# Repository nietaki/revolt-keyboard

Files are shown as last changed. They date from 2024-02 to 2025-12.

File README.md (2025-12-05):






# Revolt Keyboard

> **Revolt** - a split ergonomic keyboard prioritising ease of adoption, flexibilty, easy build+repair, and partial upgrades
> 

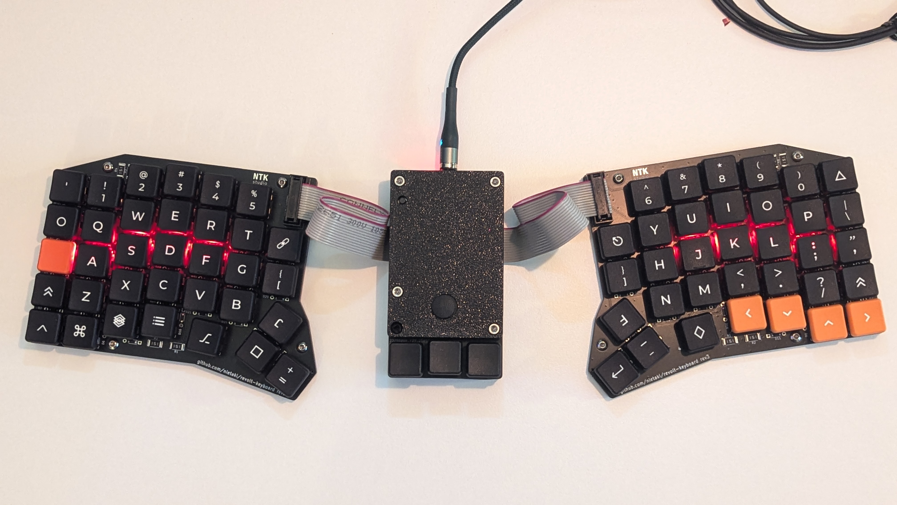
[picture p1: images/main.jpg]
final result


## Why call it “Revolt”?

1. It’s heavily inspired by [Redox](https://github.com/mattdibi/redox-keyboard), an amazing open-source keyboard, that is still my daily driver
2. It’s revolting against the popular design philosophy of keybords like Sofle, Lily58 or Corne, which prioritise a compact footprint over other qualities
3. Some might find it “revolting”, since its looks are secondary to its features

More info on the design philosophy behind revolt in the [Revolt Manifesto](./Revolt_Manifesto.md)

## TL;DR

It’s a 68(+3) key, wired, choc-based split ergonomic keyboard running QMK. Instead of being split into 2 halves, it’s split into 3 parts: left input, right input and the center one called “commander”

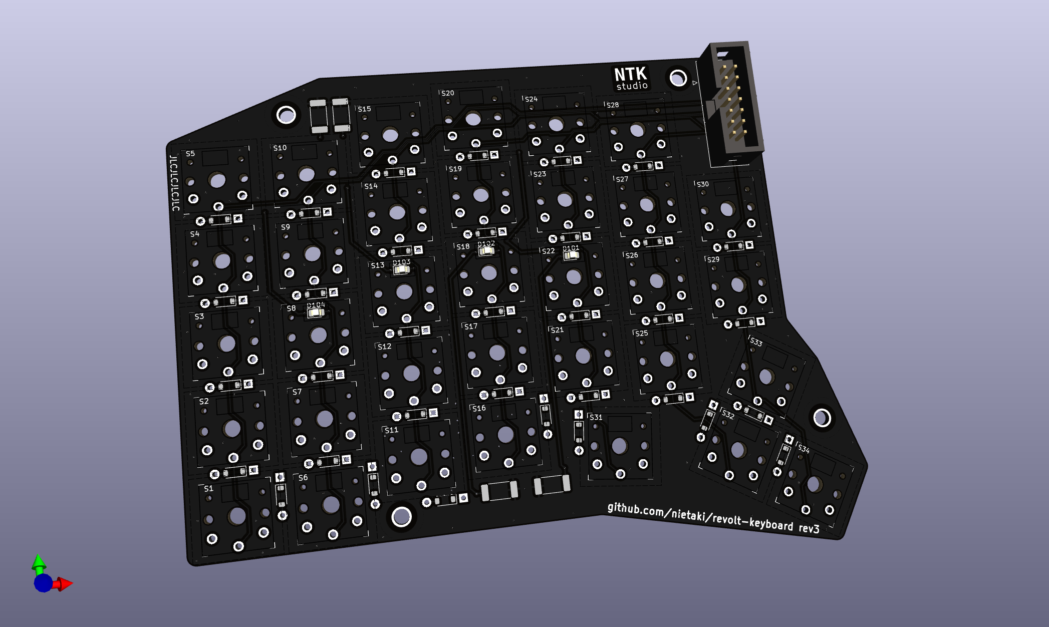
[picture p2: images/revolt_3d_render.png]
input board


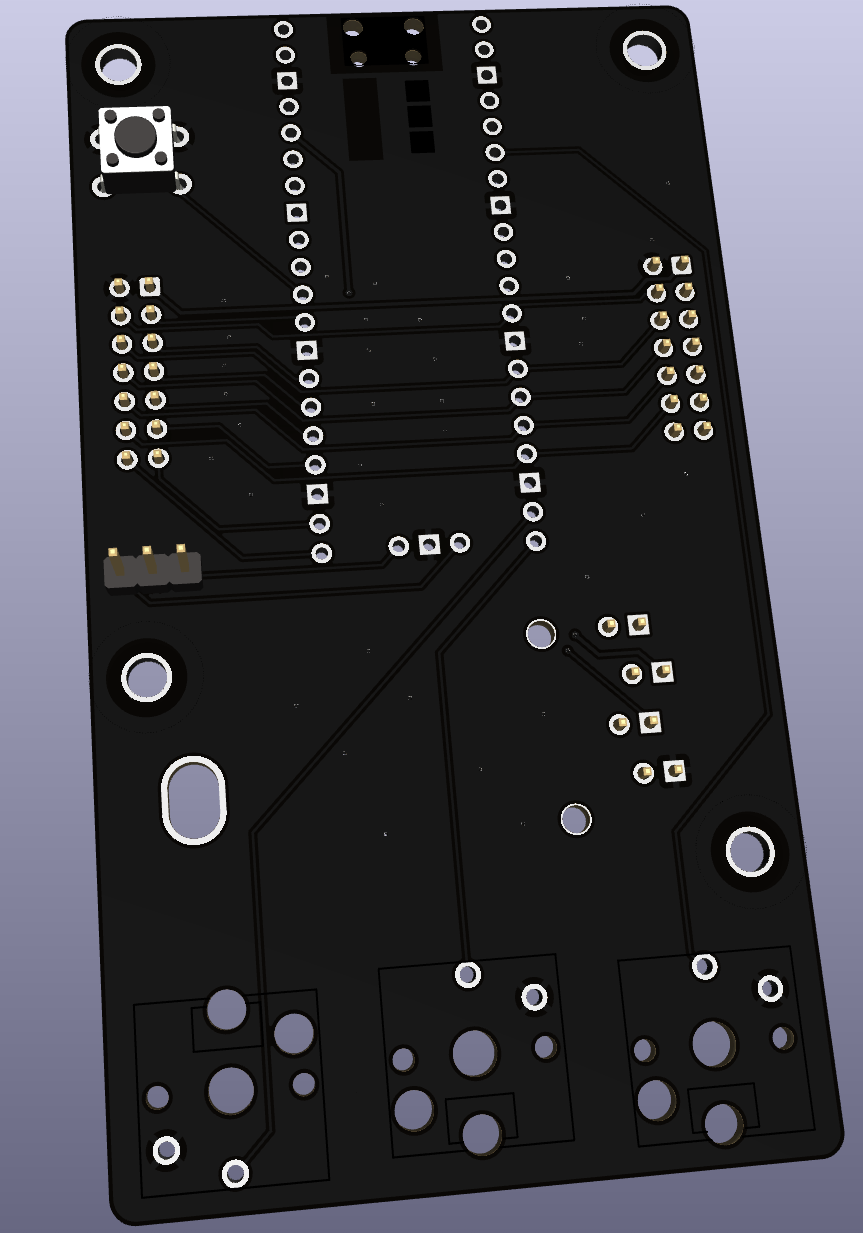
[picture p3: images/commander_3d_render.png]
commander board


The left and right input parts are “dumb”, and contain only the switches and diodes to make 7x5 matrix work, plus optional LEDs under home keys.

The case will be made with low profile + tenting in mind (with multiple tenting angles possible), with two versions: for soldered switches without a top plate and hotswap with a top plate.

The commander board should lend itself to experimenting with different pointing devices. 
Current has connectors for a PSP 3000 joystick. It should be easy to create versions that support other pointing devises, like a trackball, a Cirque touchpad or other joysticks.

## How To...

### ...build the keyboard?

Follow the [build video](https://www.youtube.com/watch?v=ghhF0bAFxww). You can find more support under the links [here](https://ntkstudio.net/products/revolt-keyboard/#support).

### ...make the cases?

The case files are available on [Printables](https://www.printables.com/model/1439208-revolt-keyboard-cases-rev1) and [Thingiverse](https://www.thingiverse.com/thing:7166363).

### ...compile the firmware?

```bash
$ cd /path/to/qmk_firmware
$ qmk compile -kb revolt/rev1 -km default
#  It should generate the firmware file
$ stat ./revolt_rev1_default.uf2
```
### ...flash the firmware?

1. Unplug the commander board
1. Push the `bootsel` button on the RP2040
1. While having the button pushed in, connect the commander board to the computer

A virtual drive (?) for the rpi should be discovered by the computer. 
Drag the compiled firmware file into it. 
RPi will reboot and run the firmware.

## FAQ

### Why do you hate Sofle/Lily58/Corne?

I don’t! They’re beautiful keyboards, designed with love and forethought, all of them with passionate communities. They just don’t fit the criteria of what I’m looking for in an ergonomic keyboard that can be used just as easily for programming and gaming, especially for people coming from “regular” keyboards. I wanted to make a keyboard that’s perfect for me and other like-minded people.

### No wireless version?

I’m not ruling out a wireless version in the future. I’d like to perfect the wired version to my liking and see what kinds of compromises make sense.

But with Revolt being open source, there’s no reason for anyone interested not to take a crack at it themselves.

## Workflow

1. Build matrix, outline and pcb in yml
2. generate kicad pcb
3. Create the kicad project
4. Replace the kicad pcb file with the generated one
5. Replace the switch footprints with the ones from keyswitch library
5. Create the matrix schematic by hand, with the diode numbers matching the swich numbers from pcb
6. **change the diode numbers in the pcb to line up with the switch numbers in the pcbnew**
  - this can be automated together with the switch numbers, I think
7. Add hierarchical net names
7. Update the schematic from the pcb band the other way until stuff is consistent.
8. ...
8. Draw the rest of the owl

## Special thanks

Projects that helped or inspired me:

- https://github.com/mattdibi/redox-keyboard
- https://github.com/daprice/keyswitches.pretty/ - adapted some footprints from this brilliant library
- https://flatfootfox.com/ergogen-introduction/
- https://github.com/labtroll/KiCad-DesignRules/tree/main
- https://docs.ergogen.xyz/
- https://github.com/sol/KiCad-RP-Pico

## License



[Revolt Keyboard](https://github.com/nietaki/revolt-keyboard)© 2024 by [@nietaki](https://nietaki.com/) is licensed under [CC BY-SA 4.0](http://creativecommons.org/licenses/by-sa/4.0/?ref=chooser-v1)

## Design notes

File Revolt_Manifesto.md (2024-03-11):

# Revolt Manifesto

## Design principles

### Enough keys to be single layer friendly

Keyboards smaller than Ergodox/Redox/Ergodash can’t fit many of the keys needed for every day use, forcing the users to rely on layers and dual-function keys. Working with a single layer 95% of the time allows you to use Revolt for anything you need it for, without crafting and memorizing shortcuts or being careful with dual-function keys.

That’s not to say you can’t use a layered setup you like - QMK allows for many layers and advanced functions, as you can see in the [configurator](https://config.qmk.fm/#/redox/rev1/base/LAYOUT).

I personally use layer 2 mainly for function keys and media keys in my Redox.

I’d argue this also has a positive impact on the typing speed. Many people argue that the main factor in the typing speed is not having to move your fingers much (with fewer keys, more layers and possibly something like the Colemak layout). I believe having to use key combos or different behaviour on key tap and key hold to input characters slows down your typing. The mental load to keep up with a complicated setup doesn’t help either. 

### Ease of adoption

People adopting Revolt can leverage their muscle memory with minimal changes, thanks to the `CTRL` and `META/WIN/CMD` keys in their regular locations and the flexibility of QMK.  

### Ergonomics

This one might seem pretty obvious, but hear me out.

The reason I first got into ergonomic keyboards was the RSI I was getting from long hours of coding early in my career - I was getting terrible wrist pain after hours of coding early in my career. I got a [Microsoft Sculpt Ergonomic Keyboard](https://www.google.com/search?q=microsoft+sculpt+ergonomic+keyboard&tbm=isch), which instantly made the problem go away.

I had a number of those throughout the years (5 keyboard+mouse sets?) and I loved them, but they kept on breaking. I got better at fixing them, cleaning and replacing the key stabilizers, but I kept having to buy new ones - and I think the keyboard is out of production by now…

This made it obvious to me I needed a mechanical keyboard that still had the ergonomics I was looking for - a stable keyboard with split layout with tenting and a good amount of keys.

I built myself a custom Redox and bought some wristpads for it - I still use it to this day. But I’d still prefer a lower profile keyboard with a pointer device in the middle (a touchpad, a trackball, or a Thinkpad-style trackpoint). 

This is where Revolt comes in - I hope I can have it all (and more) with this design

I’m trying to achieve good ergonomics with:

- Case designed with tenting in mind
- Keys closer together thanks to smaller footprints of Kailh Choc keycaps
- Keys closer to the desk surface (again thanks to Kailh Choc switches and a purpose-designed case)
- A more aggressive pinky stagger than some of the other designs

### Bang for buck

I wanted to keep the build affordable and simple, without sacrificing any of the other priorities. The simplest non-hotswap version should be doable for around 80 EUR, with not much more cost for a version with 3d-printed tenting case.

I want the design to lend itself to higher end versions, with hot-swap sockets and a top plate, integrated touchpad, and possibly 2 microcontrollers with wireless communication (all hopefully to come in future versions)

### Easy to build/fix

I’ve had keyboards in the past where the failure mode was the USB socket breaking, and replacing the microcontrollers (or reconfiguring the keyboard to connect from the other half) was more of a pain than I would like.

Similarly, there are some designs which are difficult to fix when a single component fails.

I like the idea of a “forever keyboard” that will serve you for decades with minimal maintenance. The microcontroller being on a separate PCB and easily swappable makes the whole setup quick and easy to fix in the future.

All the solder joints should be easy to access, solder or desolder without special tools. The case should be easy to make with any 3d printer.

### Function over form

Many keyboard designs prioritize minimalistic wireless aesthetics over ergonomics or other aspects of the build.

Revolt is aiming for the best long-term experience for the keyboard’s users, builders and developers while sporting an unapologetically utilitarian look.

### Easy to iterate on and (partially) upgrade

Usually the keyboard you first build/buy is the keyboard you’re stuck with, with the exception of changing switches or keycaps.

With Revolt you can keep the sides to experiment with different pointing devices in the center part, or keep the center part and play with different layouts in your left/right parts while keeping the center part that works for you. All that with minimal effort and cost.

With a standardized connection between the commander board and the input parts it’s easier, quicker and cheaper to iterate on the individual aspects of the keyboard. Want to try a new pointing device? Make some small changes to the commander board and solder it together without changing your input parts. Got an idea for a better key layout? You can make a revision of the input pcb without ever touching the microcontroller.

### Ease of layout changes / firmware programming

With most split keyboards, when you update your layout, you need to flash the firmware in both halves of the keyboard, which can be a pain and require some cable juggling. And you will be messing with the layout when you first get the keyboard :D

With a single microcontroller you don’t need to reconnect anything, you just reset the keyboard, flash it, and you’re done!

### Open source

It took a lot of open source work (KiCad, QMK, footprint libraries, microcontrollers) to make designing keyboards as easy and fun as it is right now. I’d like to pay it forward by reducing the barrier of entry for people to make a keyboard they’ll love using.

I might consider selling pre-made Revolt components, but the designs will always be open-source and anyone will be able their own unit from scratch.

## How is it different from Sofle/Lily58/Corne?

1. It has 68 keys (as opposed to 42 in Corne, 58 in Sofle and Lily58). It allows for `CTRL` and `META/WIN/CMD` keys in their regular location, arrow keys in the first layer and basically all of TKL ISO 104 keys, minus the function row and some of the  `HOME` / `END` / `PGUP` / `PGDOWN` keys
2. It has more thumb keys, in easy to reach locations
3. It uses just one microcontroller, making it easier to change the the layout/firmware

## How is it different from Redox?

1. It can be lower profile since the microcontroller isn’t mounted under the PCBs and Revolt v1 is designed with Kailh Choc switches in mind
2. It uses exclusively 1u keys, making it easier and cheaper to buy a keycap set for it. The 1.5u keys in Redox don’t have much of a benefit, but they make the overall keyboard dimensions bigger.
3. The pinky keys are placed lower to make them easier to reach - I struggle to press `Q` with my pinky on my Redox
4. All solder joints are accessible without the need to desolder the microcontroller
5. It uses just one microcontroller, making it easier to change the the layout/firmware

### How is it different from Zodiark?

> ⚠️ TODO

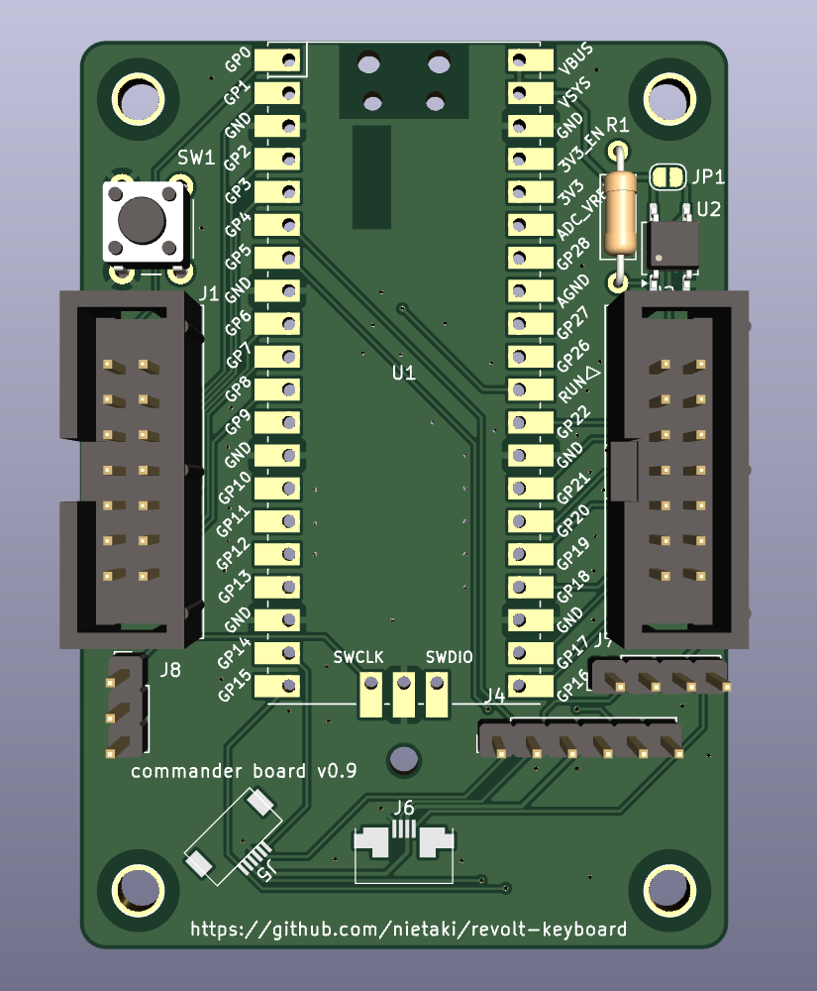
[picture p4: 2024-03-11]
images/3d_revolt_commander_0_9.png

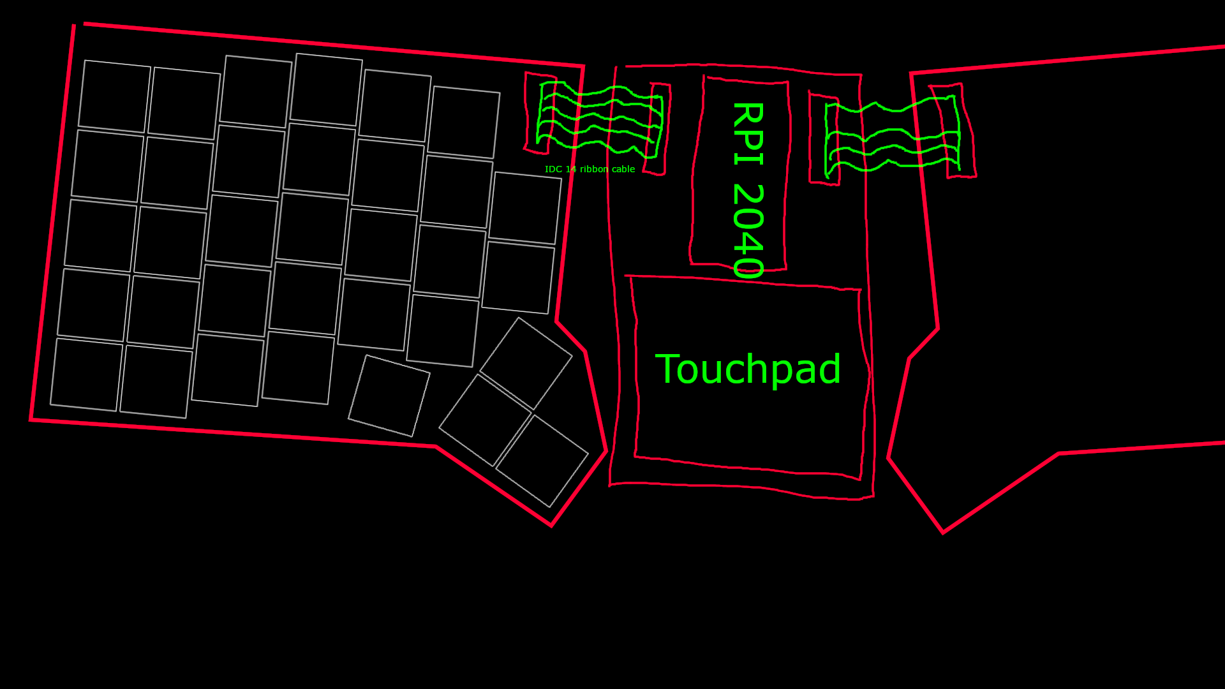
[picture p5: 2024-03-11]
images/revolt_idea.png

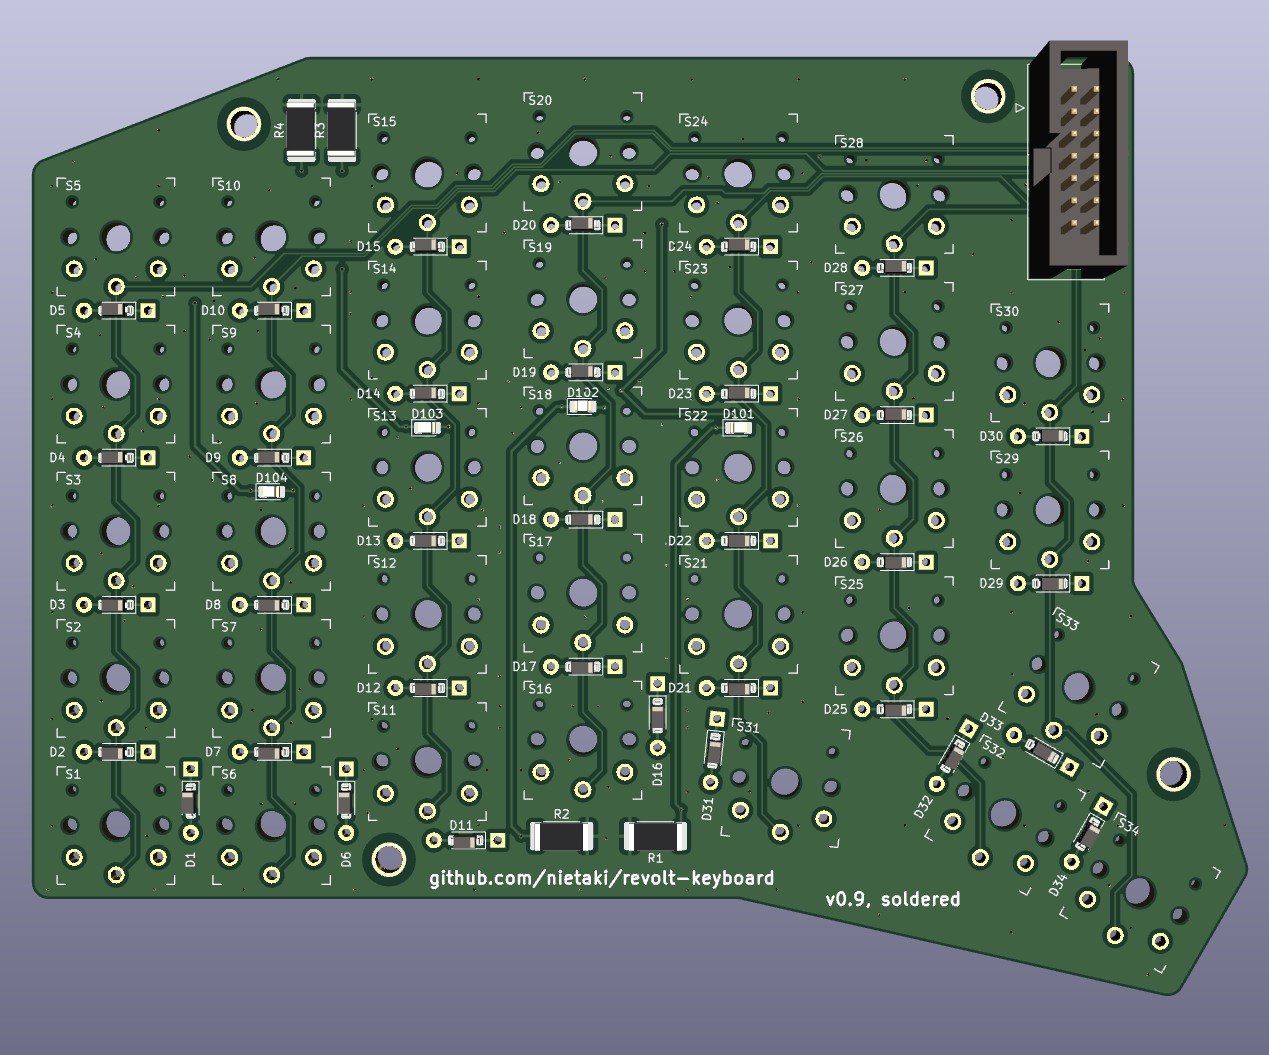
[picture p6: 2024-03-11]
images/3d_revolt_0_9.png

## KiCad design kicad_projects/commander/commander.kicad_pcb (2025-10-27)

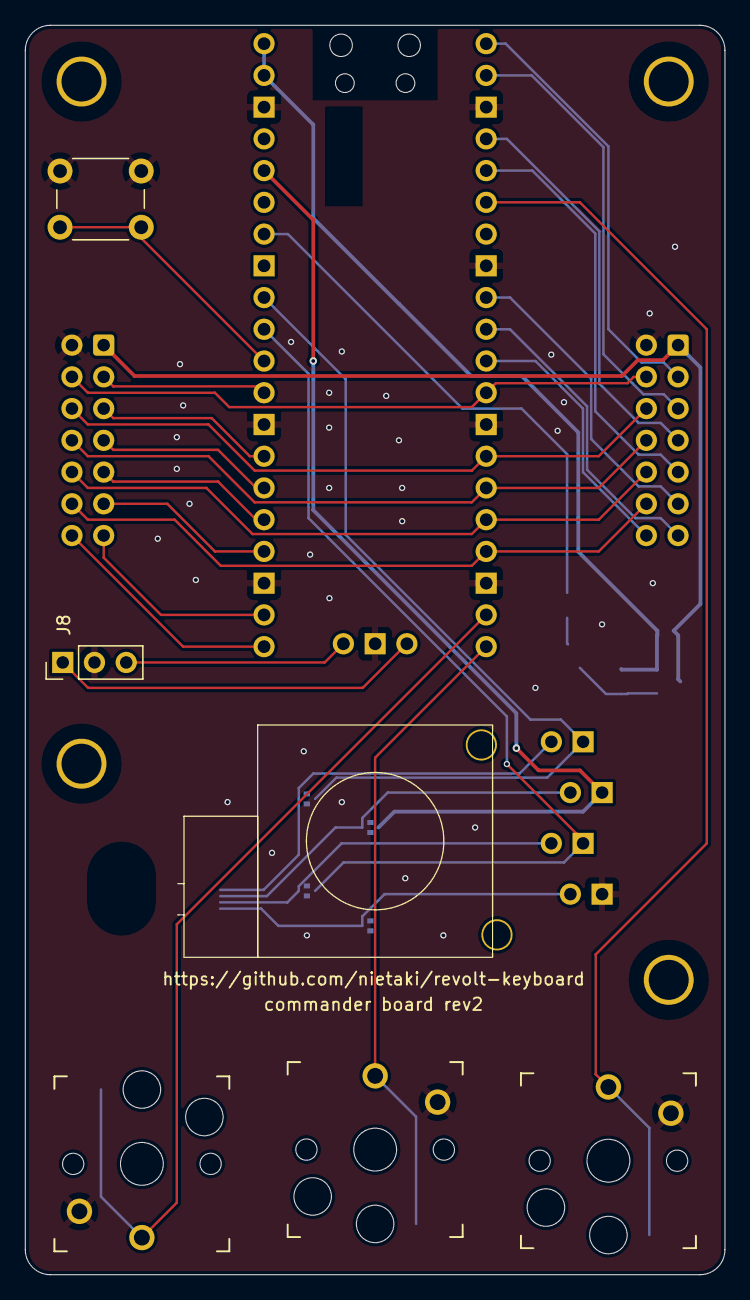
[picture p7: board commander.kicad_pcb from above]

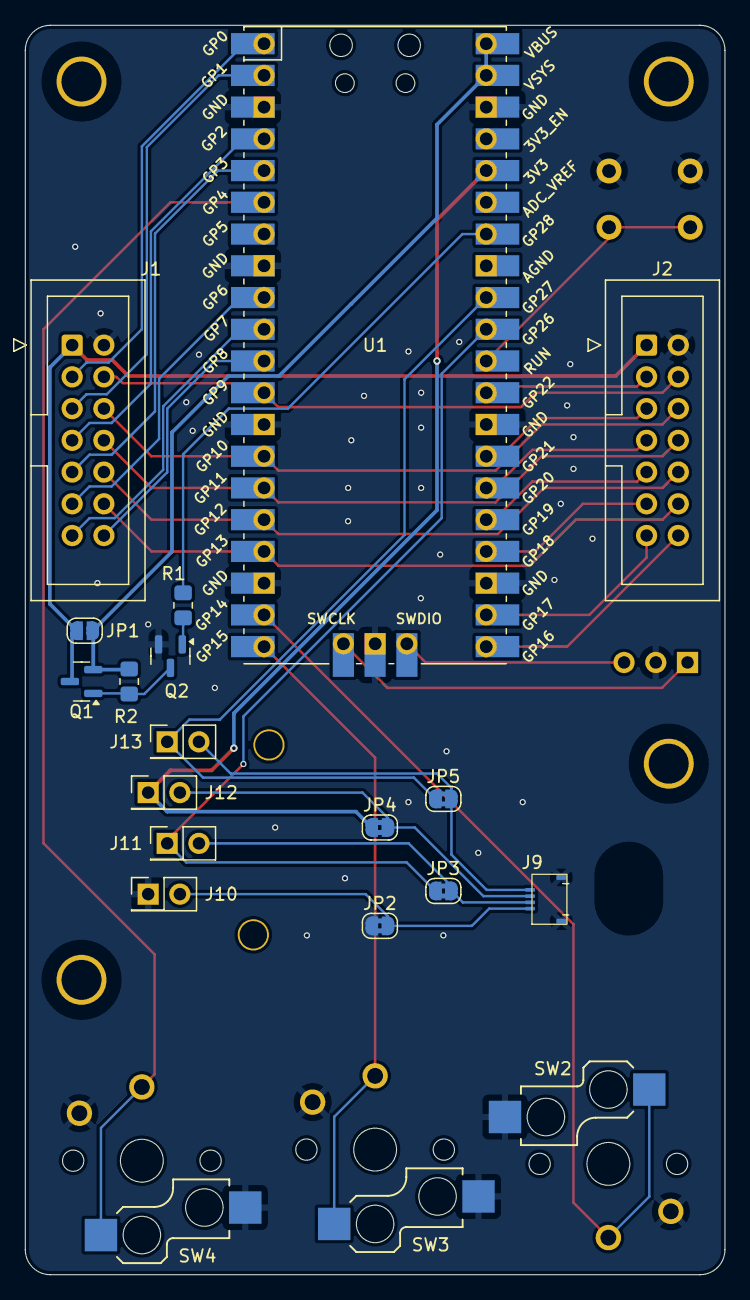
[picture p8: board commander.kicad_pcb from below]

Board: 2 copper layers, 56.0 x 100.0 mm, 27 parts (17 on the bottom side), 38 nets.

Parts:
HOLE_M3, HOLE_M3#2, HOLE_M3#3: H2; HOLE_M3
HOLE_M3#4: H1; HOLE_M3
J1: right input IDC14; IDC-Header_2x07_P2.54mm_Vertical
J2: left input IDC14; IDC-Header_2x07_P2.54mm_Vertical
J8: debug out; PinHeader_1x03_P2.54mm_Vertical
J9: HC-FPC-05-09-4RLTAG
J10, J11, J12, J13: Conn_02x01; PinHeader_2x01_P2.54mm_Vertical
JP1: SolderJumper_2_Open; SolderJumper-2_P1.3mm_Open_RoundedPad1.0x1.5mm
JP2, JP3, JP4, JP5: SolderJumper_2_Bridged; SolderJumper-2_P1.3mm_Bridged2Bar_RoundedPad1.0x1.5mm
PSP_JOY: PSP1000_JOY
Q1: AO3401A; SOT-23
Q2: NPN - MMBT2222A; SOT-23
R1: 1k; R_0805_2012Metric_Pad1.20x1.40mm_HandSolder
R2: 10k; R_0805_2012Metric_Pad1.20x1.40mm_HandSolder
SW1: RESET_SWITCH; SW_PUSH_6mm_H4.3mm
SW2, SW3, SW4: SW_Push; Kailh_socket_PG1350_optional
U1: Pico; RPi_Pico_SMD_TH

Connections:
3V3: J12.1, JP4.1 (A), U1.36 (3V3)
5V: JP1.1 (A), Q1.2 (S), R2.2, U1.39 (VSYS), U1.40 (VBUS)
/COL0: J2.3, U1.29 (GPIO22)
/COL1: J2.5, U1.27 (GPIO21)
/COL2: J2.7, U1.26 (GPIO20)
/COL3: J2.9, U1.25 (GPIO19)
/COL4: J2.11, U1.24 (GPIO18)
/COL5: J2.13, U1.22 (GPIO17)
/COL6: J2.14, U1.21 (GPIO16)
/COL7: J1.14, U1.11 (GPIO8)
/COL8: J1.13, U1.10 (GPIO7)
/COL9: J1.11, U1.9 (GPIO6)
/COL10: J1.9, U1.5 (GPIO3)
/COL11: J1.7, U1.4 (GPIO2)
/COL12: J1.5, U1.2 (GPIO1)
/COL13: J1.3, U1.1 (GPIO0)
/LED_ENABLE: R1.2, U1.34 (GPIO28_ADC2)
/LMB: SW2.1, U1.19 (GPIO14)
/MMB: SW3.1, U1.20 (GPIO15)
/RMB: SW4.1, U1.6 (GPIO4)
/ROW0: J1.12, J2.12, U1.17 (GPIO13)
/ROW1: J1.10, J2.10, U1.16 (GPIO12)
/ROW2: J1.8, J2.8, U1.15 (GPIO11)
/ROW3: J1.6, J2.6, U1.14 (GPIO10)
/ROW4: J1.4, J2.4, U1.12 (GPIO9)
/RUN: SW1.2, U1.30 (RUN)
/X1: J11.1, JP3.1 (A), U1.31 (GPIO26_ADC0)
/X2: J13.1, JP5.1 (A), U1.32 (GPIO27_ADC1)
GND: J1.2, J2.2, J8.2, J9.5 (P1), J9.6 (P2), J10.1, JP2.1 (A), Q2.2 (E), SW1.1, SW2.2, SW3.2, SW4.2, U1.3 (GND), U1.8 (GND), U1.13 (GND), U1.18 (GND), U1.23 (GND), U1.28 (GND), U1.38 (GND), U1.42 (GND)
LED_5V: J1.1, J2.1, JP1.2 (B), Q1.3 (D)
unnamed: J8.1, U1.41 (SWCLK)
unnamed: J8.3, U1.43 (SWDIO)
unnamed: J9.1, J10.2, JP2.2 (B)
unnamed: J9.2, J11.2, JP3.2 (B)
unnamed: J9.3, J12.2, JP4.2 (B)
unnamed: J9.4, J13.2, JP5.2 (B)
unnamed: Q1.1 (G), Q2.3 (C), R2.1
unnamed: Q2.1 (B), R1.1

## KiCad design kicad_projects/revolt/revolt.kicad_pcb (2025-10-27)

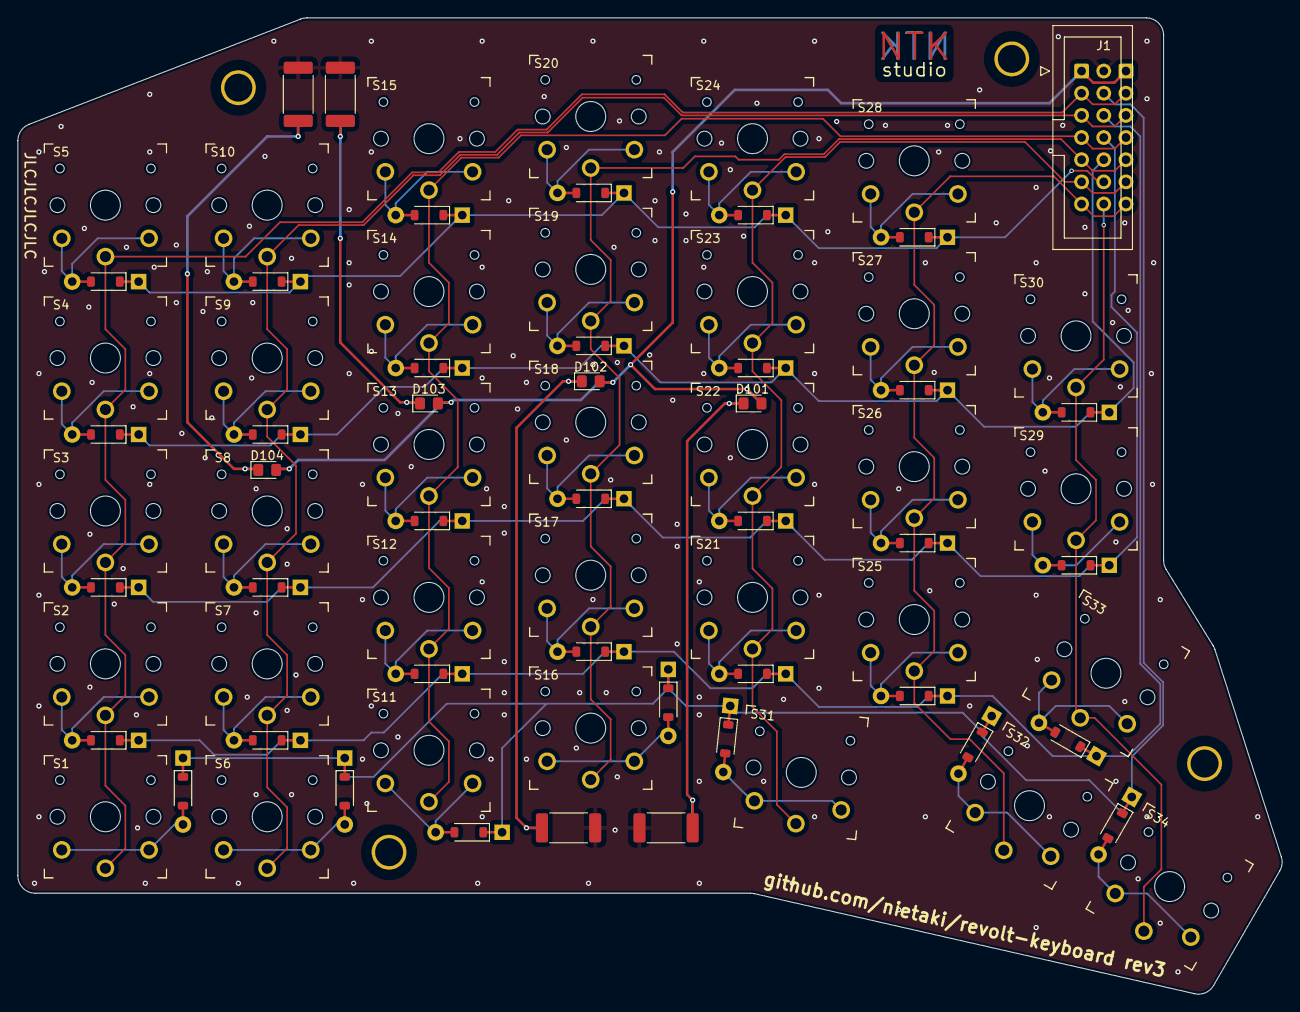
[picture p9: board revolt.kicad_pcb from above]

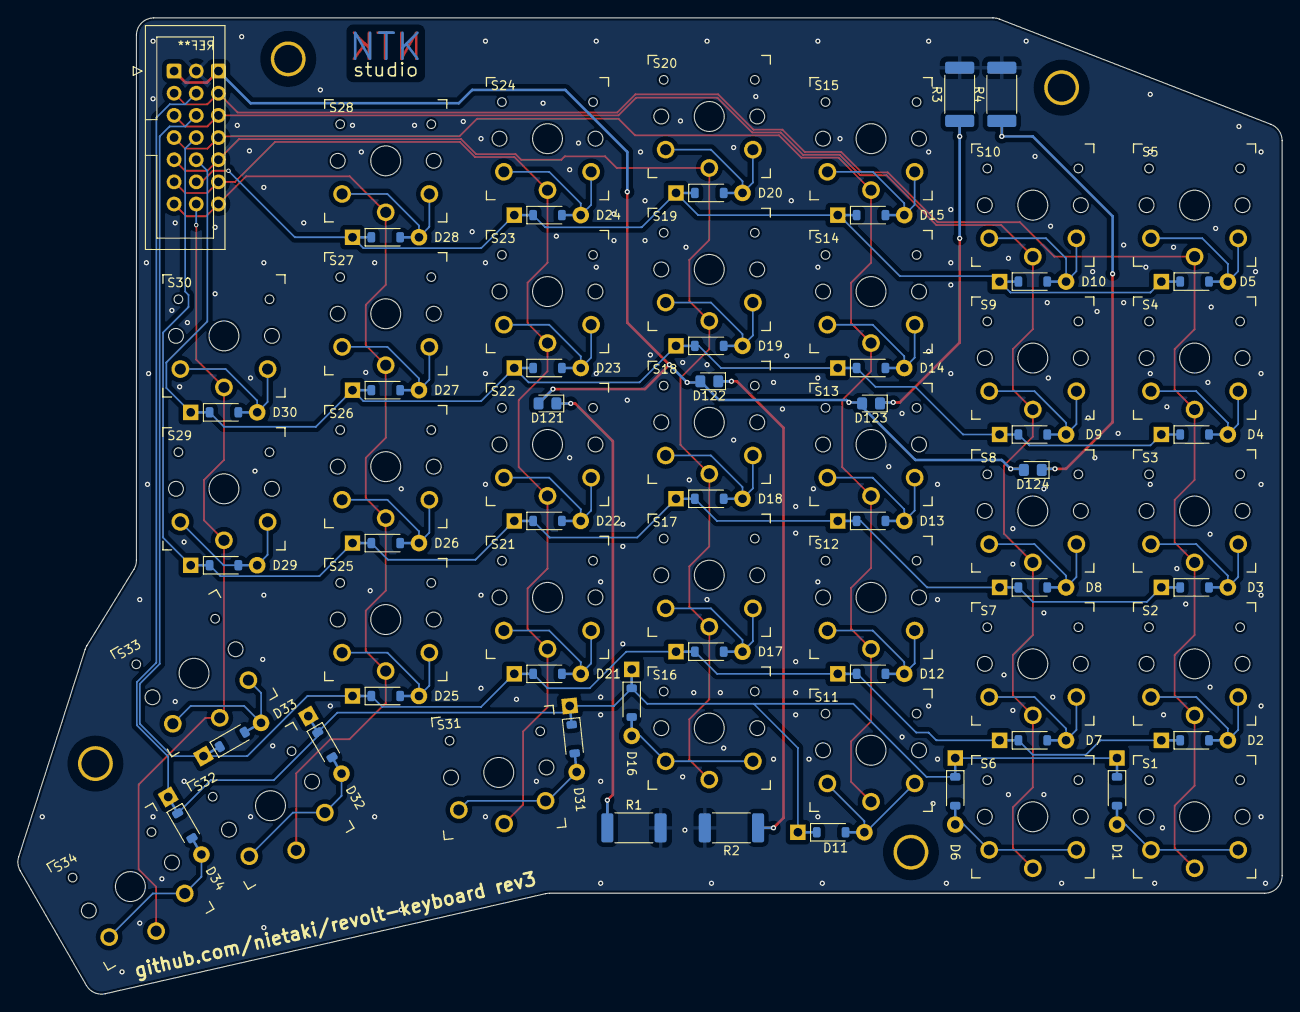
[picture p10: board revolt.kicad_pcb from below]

Board: 2 copper layers, 144.9 x 111.9 mm, 85 parts (42 on the bottom side), 52 nets.

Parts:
D1, D2, D3, D4, D5, D6, D7, D8, D9, D10, D11, D12, D13, D14, D15, D16, D17, D18, D19, D20, D21, D22, D23, D24, D25, D26, D27, D28, D29, D30, D31, D32, D33, D34: D_SOD-123-combo-reversible
D101, D102, D103, D104, D121, D122, D123, D124: LED; LED_0805_2012Metric_Pad1.15x1.40mm_HandSolder
H1, H2, H3, H4: MountingHole; HOLE_M3
J1: IDC-Header_2x07_P2.54mm_Vertical_Reversible
R1, R2, R3, R4: 150; R_2512_6332Metric_Pad1.40x3.35mm_HandSolder_reversible
S1, S2, S3, S4, S5, S6, S7, S8, S9, S10, S11, S12, S13, S14, S15, S16, S17, S18, S19, S20, S21, S22, S23, S24, S25, S26, S27, S28, S29, S30, S31, S32, S33, S34: SW_PG1350_reversible_with_keycap_outline

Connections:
5V: D101.2 (A), D102.2 (A), D103.2 (A), D104.2 (A), D121.2 (A), D122.2 (A), D123.2 (A), D124.2 (A), J1.1
/COL0: J1.3, S1.1, S2.1, S3.1, S4.1, S5.1
/COL1: J1.5, S6.1, S7.1, S8.1, S9.1, S10.1
/COL2: J1.7, S11.1, S12.1, S13.1, S14.1, S15.1
/COL3: J1.9, S16.1, S17.1, S18.1, S19.1, S20.1
/COL4: J1.11, S21.1, S22.1, S23.1, S24.1, S31.1
/COL5: J1.13, S25.1, S26.1, S27.1, S28.1, S32.1
/COL6: J1.14, S29.1, S30.1, S33.1, S34.1
/ROW0: D5.1 (K), D10.1 (K), D15.1 (K), D20.1 (K), D24.1 (K), D28.1 (K), J1.12
/ROW1: D4.1 (K), D9.1 (K), D14.1 (K), D19.1 (K), D23.1 (K), D27.1 (K), D30.1 (K), J1.10
/ROW2: D3.1 (K), D8.1 (K), D13.1 (K), D18.1 (K), D22.1 (K), D26.1 (K), D29.1 (K), J1.8
/ROW3: D2.1 (K), D7.1 (K), D12.1 (K), D17.1 (K), D21.1 (K), D25.1 (K), D33.1 (K), J1.6
/ROW4: D1.1 (K), D6.1 (K), D11.1 (K), D16.1 (K), D31.1 (K), D32.1 (K), D34.1 (K), J1.4
GND: J1.2, R1.2, R2.2, R3.2, R4.2
unnamed: D1.2 (A), S1.2
unnamed: D2.2 (A), S2.2
unnamed: D3.2 (A), S3.2
unnamed: D4.2 (A), S4.2
unnamed: D5.2 (A), S5.2
unnamed: D6.2 (A), S6.2
unnamed: D7.2 (A), S7.2
unnamed: D8.2 (A), S8.2
unnamed: D9.2 (A), S9.2
unnamed: D10.2 (A), S10.2
unnamed: D11.2 (A), S11.2
unnamed: D12.2 (A), S12.2
unnamed: D13.2 (A), S13.2
unnamed: D14.2 (A), S14.2
unnamed: D15.2 (A), S15.2
unnamed: D16.2 (A), S16.2
unnamed: D17.2 (A), S17.2
unnamed: D18.2 (A), S18.2
unnamed: D19.2 (A), S19.2
unnamed: D20.2 (A), S20.2
unnamed: D21.2 (A), S21.2
unnamed: D22.2 (A), S22.2
unnamed: D23.2 (A), S23.2
unnamed: D24.2 (A), S24.2
unnamed: D25.2 (A), S25.2
unnamed: D26.2 (A), S26.2
unnamed: D27.2 (A), S27.2
unnamed: D28.2 (A), S28.2
unnamed: D29.2 (A), S29.2
unnamed: D30.2 (A), S30.2
unnamed: D31.2 (A), S31.2
unnamed: D32.2 (A), S32.2
unnamed: D33.2 (A), S33.2
unnamed: D34.2 (A), S34.2
unnamed: D101.1 (K), D121.1 (K), R1.1
unnamed: D102.1 (K), D122.1 (K), R2.1
unnamed: D103.1 (K), D123.1 (K), R3.1
unnamed: D104.1 (K), D124.1 (K), R4.1

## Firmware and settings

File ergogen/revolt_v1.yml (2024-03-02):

units:
  # choc spacing is usually 18x17mm
  # vertical spacing, center to center
  # 17.526 = 6.9 * 2.54, leaving about 0.9mm spacig between keycaps
  py: 17.526
  $default_padding: 17.526
  # 18.542 = 7.3 * 2.54
  px: 18.542
  $default_spread: 18.542

  $default_width: 18
  $default_height: 17
  # Once a point within a column is determined, 
  # padding represents the vertical gap between it and the next row. 
  
  # tenth of an inch
  dec: 2.54
  mil: dec / 100
  ring_stagger: dec * 3
  middle_stagger: dec
  index_stagger: -dec
  # redox had 1.905mm, 0.6 * dec = 1.524, 0.7 ~ 1.778
  inner_stagger: -dec
  screwhead_radius: 5.8 / 2
  extra_top_space: dec
  extra_bottom_space: 0
  extra_left_space: 30 * mil
  extra_right_space: 30 * mil
  connector_width: 450 * mil 
  connector_height: 26.440
points:
  zones:
    matrix:
      anchor:
        shift: [40 * dec, -60 * dec]
      columns:
        outer:
          key.column_net: COL0
          rows.mod.tags: custom_diode_right
        pinky:
          key.column_net: COL1
          rows.mod.tags: custom_diode_right
        ring:
          key:
            stagger: ring_stagger
            column_net: COL2
        middle:
          key:
            stagger: middle_stagger
            column_net: COL3
          rows.mod.tags: custom_diode_right
        index:
          key:
            stagger: index_stagger
            column_net: COL4
          rows.mod.skip: true
        inner:
          key:
            stagger: inner_stagger
            column_net: COL5
          rows.mod.skip: true
      rows:
        mod:
          row_net: ROW4
        bottom:
          row_net: ROW3
        home:
          row_net: ROW2
        top:
          row_net: ROW1
        num:
          row_net: ROW0
    bonus:
      anchor:
        ref: matrix_inner_home
        shift: [px, -dec * 1]
      columns:
        bonus:
          key.column_net: COL6
      rows:
        home:
          row_net: ROW2
        top:
          row_net: ROW1
    alt:
      anchor:
        ref: matrix_index_mod 
      columns:
        index:
          key.column_net: COL4
          rows.mod:
            shift: [dec * 2.2, -dec]
            rotate: -6
            tags: custom_diode_left
      rows:
        mod:
          row_net: ROW4
    thumb:
      anchor:
        ref: matrix_inner_bottom
        shift: [dec * 5.2, -dec * 8.4]
        rotate: -30
      columns:
        close:
          rows.top.row_net: ROW3
          rows.top.column_net: COL6
          rows.home.row_net: ROW4
          rows.home.column_net: COL5
          rows.home.tags: custom_diode_left
        far:
          rows.home.row_net: ROW4
          rows.home.column_net: COL6
          rows.home.tags: custom_diode_left
          rows.top.skip: true
      rows:
        home:
        top:
outlines:
  keys:
    - what: rectangle
      where: true
      size: [18, 17]
  connector:
    - what: rectangle
      adjust.shift: [dec * 1.4, 0.5 * 17 + 1 + connector_height * 0.5]
      adjust.rotate: 30 * 0
      size: [connector_width, connector_height]
      where:
        ref: bonus_bonus_top
     
  screwhead:
    - what: circle
      radius: screwhead_radius
      adjust.shift: [12, 11]
      where:
        ref: matrix_inner_num
  screwhead2: # bottom left
    - what: circle
      radius: screwhead_radius
      adjust.shift: [-5, -14]
      where:
        ref: matrix_middle_mod
  screwhead3:
    - what: circle
      radius: screwhead_radius
      adjust.shift: [14, -3]
      where:
        ref: thumb_close_top
  screwhead4: # top left
    - what: circle
      radius: screwhead_radius
      adjust.shift: [4, 16]
      where:
        ref: matrix_pinky_num
  board:
    - what: polygon
      bound: true
      # operation: stack
      points:
        # bottom left
        - ref: matrix_outer_mod
          shift: [-0.5px - extra_left_space, -0.5py - extra_bottom_space]
        # top left
        - ref: matrix_outer_num
          shift: [-0.5px - extra_left_space, 0.5py]
        # top left kink
        - ref: matrix_middle_num
          shift: [-1.5px - 2dec, 0.5py + extra_top_space]
        - ref: matrix_middle_num
          shift: [ 3 * px + 0.5px + extra_right_space, 0.5py + extra_top_space]
        - ref: bonus_bonus_home
          shift: [0.5px + extra_right_space, -0.5py]
        #- ref: thumb_close_top
        #  shift: [0px, 0.5py]
        - ref: thumb_close_top
          shift: [0.5px, 0.5py]
        - ref: thumb_far_home
          shift: [0.5px + extra_right_space, +0.5py]
        - ref: thumb_far_home
          shift: [0.5px + extra_right_space, -0.5py]
        # bottom kink
        - ref: matrix_outer_mod
          shift: [4px - 0px, -0.5py - extra_bottom_space]
        #- ref: matrix_outer_mod
        #  shift: [3px + 1px, -0.5py]
  board_fillet:
    - what: outline
      name: board
      fillet: 2
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

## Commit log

2024-02-25 Moving things around a bit, screws roughly valid now
2024-02-25 PCB first tries
2024-02-25 kicad project, no schematic
    [revolt.kicad_pcb, revolt.kicad_pcb.bak.kicad_pcb, revolt.kicad_sch]
2024-02-26 add matrix to the schematic, minus the net names
    [revolt.kicad_pcb, revolt.kicad_sch]
2024-02-26 Update the diode numbers
    [revolt.kicad_pcb]
2024-02-26 fix pcb diode numbers
    [revolt.kicad_pcb]
2024-02-26 fixed pcb and schematic
    [revolt.kicad_pcb, revolt.kicad_sch]
2024-02-26 todos, remove fp info cache
    [revolt.kicad_pcb, revolt.kicad_sch]
2024-02-27 Add design rules (in more ways than one)
    [design_rules.kicad_pcb, revolt.kicad_pcb.bak.kicad_pcb]
2024-02-29 Add library with custom footprints
    [revolt.kicad_pcb]
2024-03-01 Make the outline universal for hotswap and regular switches
    [revolt.kicad_pcb]
2024-03-02 Finalize the pcb dimensions
2024-03-02 Add a reversible diode footprint for keyboards with top plate
2024-03-04 Base design, need to unify and double-check DRD rules
    [revolt.kicad_pcb, revolt.kicad_sch]
2024-03-06 Improved diodes, LED schematic
    [revolt.kicad_pcb, revolt.kicad_sch]
2024-03-06 Final footprints, schematic fixes, LEDs positioned
    [revolt.kicad_pcb, revolt.kicad_sch]
2024-03-07 Start routing the board
    [revolt.kicad_pcb, revolt.kicad_sch]
2024-03-07 Route everything but the ground plane
    [revolt.kicad_pcb]
2024-03-08 Ground plane and stitching
    [revolt.kicad_pcb]
2024-03-08 Add the url on the silkscreen, more stitching
    [revolt.kicad_pcb]
2024-03-08 Cosmetic changes
    [revolt.kicad_pcb]
2024-03-10 Commander board
    [commander.kicad_pcb, commander.kicad_sch, revolt.kicad_pcb]
2024-03-10 Commander board passing DRC
    [commander.kicad_pcb, commander.kicad_sch, revolt.kicad_pcb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]
2024-03-10 Add silkscreen info, some more routing
    [commander.kicad_pcb]
2024-03-11 Clean up some vias, 0.25mm spacing of power nets for cleaner zone fills
    [commander.kicad_pcb, revolt.kicad_pcb]
2024-04-02 Replace a relay with a MOSFET (like a pro)
    [commander.kicad_pcb, commander.kicad_sch]
2024-04-08 Production files generation
    [commander.kicad_pcb, revolt.kicad_pcb]
2025-05-14 big commander WIP
    [commander.kicad_pcb, commander.kicad_sch, revolt.kicad_pcb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]
2025-05-15 trackpoint socket footprints
    [commander.kicad_pcb, commander.kicad_sch]
2025-05-25 WIP on the new footprint
    [commander.kicad_pcb]
2025-05-26 commander board rev2, pre-manufacture
    [commander.kicad_pcb, commander.kicad_sch]
2025-05-26 commander rev2 production files
    [bom.csv, commander.kicad_pcb, commander.kicad_sch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]
2025-07-31 Correct Column net names
    [commander.kicad_pcb, commander.kicad_sch]
2025-10-27 Update to the latest files
    [bom.csv, commander.kicad_pcb, designators.csv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]
2025-12-05 Add build and case info
